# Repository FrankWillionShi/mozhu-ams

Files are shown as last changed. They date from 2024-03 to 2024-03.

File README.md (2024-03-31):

# MOZHU-AMS

#### 介绍
这是一个DIY 3D打印多色供料系统的项目，主要针对的是拓竹的P1系列，理论上X1系列也是可以用的。
输入图片说明 完整效果
这是项目第一次测试通过并且实现自动换料打印时拍摄的完整系统图片  
输入图片说明

#### 引用项目
该项目引用了B站up主不死鳥の守り的DIY AMS项目，非常感谢他开源的基于拓竹MQTT接口进行通信的设计方案和硬件结构设计，本方案才能最终落地  

输入图片说明 屏幕截图  
在本项目中，引用了这位UP主的AMS模型设计（1.2版）和拓竹MQTT的部分指令，模型设计在本开源项目的hardware文件夹中的AMS组件.3mf中，MQTT指令在代码中有所体现。

#### 项目说明

1.  本项目使用无上位机的设计，使用合宙esp32C3核心板作为主控，理论上一个主控可以控制最多四个通道的耗材。
2.  本项目为开源项目，欢迎所有对此感兴趣的人一起建设。
3.  本项目还有许多不完善的地方，日后会陆续完善，欢迎大家批评指导。

#### 文件说明

1.  hardware文件夹中包含了引用的AMS进退料组件模型，进料缓冲器模型和断料检测模型，五通受限于本人建模技术较差，是买的成品，理论上可以直接买一个A1的五通拿来用。
2.  software文件夹中包含了本项目中使用到的代码，其中filamentChange.gcode是用来替换拓竹的换料GCODE的，直接在打印机设置中复制替换就可以，主要作用是降低换料过程的复杂性，这段代码可以让打印机完成切料、退料、进料、冲洗。请注意，直接编写GCODE控制打印机是很危险的，操作不当会有很大可能导致打印机出现机械故障，所以你如果对3D打印机的gcode没有深入了解，请尽量不要做修改。software中的AMSwithESP32是本项目的代码，基于Arduino IDE编写，其中包含了一个defines.h，这个文件中包含着用户设置，使用前请在这里设置wifi SSID、密码、打印机IP、打印机的链接授权码（八位数字）以及使用的通道数量，请尽可能不要修改除user setting以外的其他设置，否则有可能导致代码无法正常运行。
3.bambu_ca.pem是本开原作者提取到自己打印机中的CA证书，并用其生成了finger point来连接打印机，如果你连上网以后无法连接到打印机的MQTT端口，在确认IP没有出错的前提下，可以使用以下指令来生成finger point并对代码进行修改：  
openssl s_client -connect your_server_address:port -showcerts | openssl x509 -noout -fingerprint

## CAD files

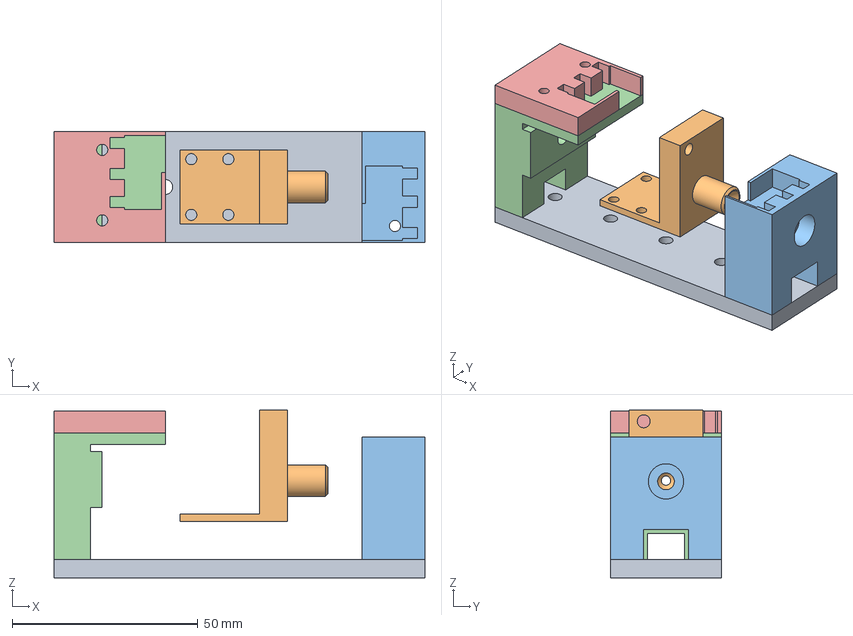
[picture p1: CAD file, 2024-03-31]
hardware/进料缓冲器.3mf
100.0 x 30.0 x 45.2 mm

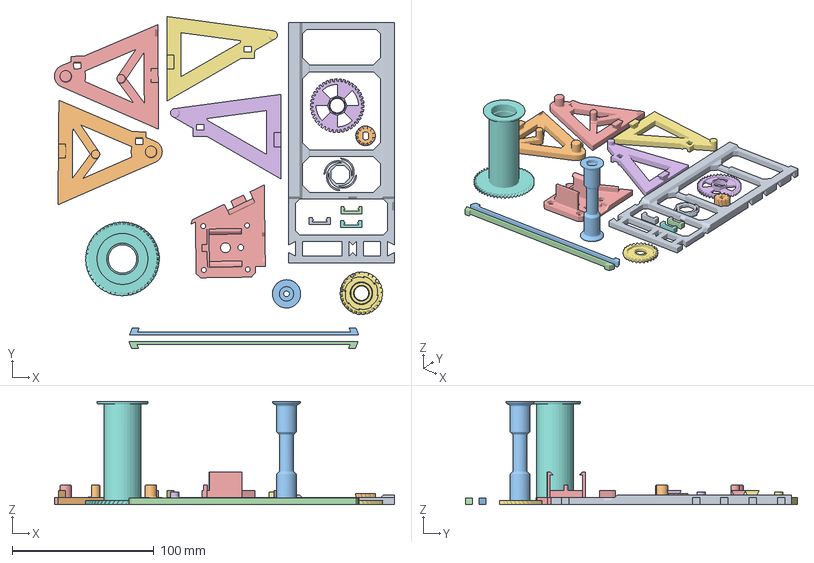
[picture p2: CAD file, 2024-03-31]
hardware/AMS组件.3mf
240.2 x 234.4 x 73.0 mm
底座
侧边 主动(单边) x 2
加强筋 1 x 2
电机固定座
棘轮 外
棘轮 内
滚轮 主动
棘轮 中
电机轴齿
滚轮 被动
缓冲器卡扣 x 3
侧边 被动(单边 右侧) x 2

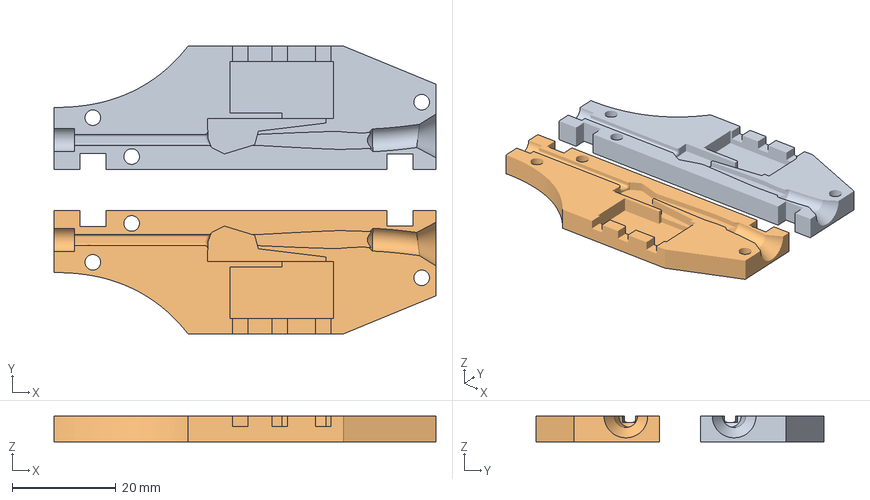
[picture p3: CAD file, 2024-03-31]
hardware/断料检测器.3mf
73.8 x 55.6 x 5.00 mm

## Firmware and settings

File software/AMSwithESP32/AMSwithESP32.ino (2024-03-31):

#define ASYNC_TCP_SSL_ENABLED 1
#define MQTT_SECURE 1
#include "defines.h"
#include <WiFi.h>
#include <ArduinoJson.h>
#include <AsyncMQTT_ESP32.h>
extern "C"
{
#include "freertos/FreeRTOS.h"
#include "freertos/timers.h"
}



//*******************Global Parameters begin********************
AsyncMqttClient mqttClient;
TimerHandle_t mqttReconnectTimer;
TimerHandle_t wifiReconnectTimer;
int Filament_Now = 0;
int FilaMent_Next = -1;
uint8_t workstate = 0;
bool Buffer_Func_Flag = 0;
bool ams_require_received = 0;
bool buffer_once_flag = 0;
const std::string bambu_resume = R"({"print":{"command":"resume","sequence_id":"1"},"user_id":"1"})";
const std::string bambu_unload = R"({"print":{"command":"ams_change_filament","curr_temp":220,"sequence_id":"1","tar_temp":220,"target":255},"user_id":"1"})";
const std::string bambu_load = R"({"print":{"command":"ams_change_filament","curr_temp":220,"sequence_id":"1","tar_temp":220,"target":254},"user_id":"1"})";
const std::string bambu_done = R"({"print":{"command":"ams_control","param":"done","sequence_id":"1"},"user_id":"1"})";
bool mqttDataReadyFlag = 0;
JsonDocument jsonRecv;
bool unloadFlag = 0;
bool sameFilamentFlag = 0;
int unloadCount = 0;
bool resumeCallbackFlag = 0;
int pwmtimer = 0;
//*******************Global Parameters end*********************

//*******************private functions begin*******************
void systeminit();
void connectToWifi();
void connectToMqtt();
void WiFiEvent(WiFiEvent_t event);
void printSeparationLine();
void onMqttConnect(bool sessionPresent);
void onMqttDisconnect(AsyncMqttClientDisconnectReason reason);
void onMqttSubscribe(const uint16_t& packetId, const uint8_t& qos);
void onMqttUnsubscribe(const uint16_t& packetId);
void onMqttMessage(char* topic, char* payload, const AsyncMqttClientMessageProperties& properties,
                   const size_t& len, const size_t& index, const size_t& total);
void onMqttPublish(const uint16_t& packetId);
void filament_buffer_func();
bool checkPauseFlag(JsonDocument& doc);
bool checkNextFilament(JsonDocument& doc,int& nextfilament);
void coreThread();
bool sendResaumeCallback();
bool checkHWSwitch(JsonDocument& doc);
void unloadBufferCallback();
void PWMGenerate(int GPIO,int threshold);
void PWMTimer();
//*******************private functions end*********************

void setup()
{
  systeminit();
}

void loop()
{
  coreThread();
}

void systeminit()
{
  // init string
  Listen_Topic = std::string("device/") + BambuLab_Serial + Listen_Topic;
  Public_Topic = std::string("device/") + BambuLab_Serial + Public_Topic;

  // init serial and print version data
  Serial.begin(115200);

  while (!Serial && millis() < 5000);

  delay(500);

  Serial.print("\n[log]Starting mozhu-AMS on ");
  Serial.println(ARDUINO_BOARD);
  Serial.print("[log]");
  Serial.println(ASYNC_MQTT_ESP32_VERSION);

  // init timer
  mqttReconnectTimer = xTimerCreate("mqttTimer", pdMS_TO_TICKS(2000), pdFALSE, (void*)0,
                                    reinterpret_cast<TimerCallbackFunction_t>(connectToMqtt));
  wifiReconnectTimer = xTimerCreate("wifiTimer", pdMS_TO_TICKS(2000), pdFALSE, (void*)0,
                                    reinterpret_cast<TimerCallbackFunction_t>(connectToWifi));

  //init callback
  WiFi.onEvent(WiFiEvent);

  mqttClient.setCredentials(username,password);
  mqttClient.onConnect(onMqttConnect);
  mqttClient.onDisconnect(onMqttDisconnect);
  mqttClient.onSubscribe(onMqttSubscribe);
  mqttClient.onUnsubscribe(onMqttUnsubscribe);
  mqttClient.onMessage(onMqttMessage);
  mqttClient.onPublish(onMqttPublish);

  //init server
  mqttClient.setServer(MQTT_HOST, MQTT_PORT);

  mqttClient.setSecure(MQTT_SECURE);

  if (MQTT_SECURE)
  {
    //mqttClient.addServerFingerprint((const uint8_t[])MQTT_SERVER_FINGERPRINT);
    mqttClient.addServerFingerprint((const uint8_t *)MQTT_SERVER_FINGERPRINT);
  }

  connectToWifi();

  //init GPIO
  for(int i = 0; i < 4; i++)
  {
    pinMode(Motor_Forward[i],OUTPUT);
    digitalWrite(Motor_Forward[i],0);
    pinMode(Motor_Bacword[i],OUTPUT);
    digitalWrite(Motor_Bacword[i],0);
    pinMode(Filament_detection[i],INPUT_PULLDOWN);
  }
  pinMode(Buffer_Detection[0],INPUT_PULLDOWN);
  pinMode(Buffer_Detection[1],INPUT_PULLDOWN);
  Serial.println("[log]GPIO init complete\n");

  //init filament
  if(!JUMP_FILAMENT_INIT)
  {
    if(Filament_Num > 4)
      Filament_Num = 4;
    if(Filament_Num < 1)
      Filament_Num = 1;
    for(int i = 0; i < Filament_Num; i++)
    {
      //make sure the filament is installed correctly
      Serial.print("[log]Filament No.");
      Serial.print(i);
      Serial.println("input");
      digitalWrite(Motor_Forward[i], 1);
      while(!digitalRead(Filament_detection[i])) {};
      Serial.print("[log]Filament No.");
      Serial.print(i);
      Serial.println("output");
      digitalWrite(Motor_Forward[i],0);
      digitalWrite(Motor_Bacword[i],1);
      while(digitalRead(Filament_detection[i])) {};
      digitalWrite(Motor_Bacword[i],0);
      Serial.print("[log]Filament No.");
      Serial.print(i);
      Serial.println("complete");
    }
    Serial.println("[log]filament init complete\n");
  }

}

void connectToWifi()
{
  Serial.println("[log]Connecting to Wi-Fi...");
  WiFi.begin(WIFI_SSID, WIFI_PASSWORD);
}

void connectToMqtt()
{
  Serial.println("[log]Connecting to MQTT...");
  mqttClient.connect();
}

void WiFiEvent(WiFiEvent_t event)
{
  switch (event)
  {
#if USING_CORE_ESP32_CORE_V200_PLUS

    case ARDUINO_EVENT_WIFI_READY:
      Serial.println("[log]WiFi ready");
      break;

    case ARDUINO_EVENT_WIFI_STA_START:
      Serial.println("[log]WiFi STA starting");
      break;

    case ARDUINO_EVENT_WIFI_STA_CONNECTED:
      Serial.println("[log]WiFi STA connected");
      break;

    case ARDUINO_EVENT_WIFI_STA_GOT_IP6:
    case ARDUINO_EVENT_WIFI_STA_GOT_IP:
      Serial.println("[log]WiFi connected");
      Serial.print("[log]IP address: ");
      Serial.println(WiFi.localIP());
      connectToMqtt();
      break;

    case ARDUINO_EVENT_WIFI_STA_LOST_IP:
      Serial.println("[log]WiFi lost IP");
      break;

    case ARDUINO_EVENT_WIFI_STA_DISCONNECTED:
      Serial.println("[log]WiFi lost connection");
      xTimerStop(mqttReconnectTimer, 0); // ensure we don't reconnect to MQTT while reconnecting to Wi-Fi
      xTimerStart(wifiReconnectTimer, 0);
      break;
#else

    case SYSTEM_EVENT_STA_GOT_IP:
      Serial.println("[log]WiFi connected");
      Serial.print("[log]IP address: ");
      Serial.println(WiFi.localIP());
      connectToMqtt();
      break;

    case SYSTEM_EVENT_STA_DISCONNECTED:
      Serial.println("[log]WiFi lost connection");
      xTimerStop(mqttReconnectTimer, 0); // ensure we don't reconnect to MQTT while reconnecting to Wi-Fi
      xTimerStart(wifiReconnectTimer, 0);
      break;
#endif

    default:
      break;
  }
}

void printSeparationLine()
{
  Serial.println("************************************************");
}

void onMqttConnect(bool sessionPresent)
{
  Serial.print("[log]Connected to MQTT broker: ");
  Serial.print(MQTT_HOST);
  Serial.print(", port: ");
  Serial.println(MQTT_PORT);
  Serial.print("PubTopic: ");
  Serial.println(Listen_Topic.c_str());

  printSeparationLine();
  Serial.print("[log]Session present: ");
  Serial.println(sessionPresent);

  uint16_t packetIdSub = mqttClient.subscribe(Listen_Topic.c_str(), 0);
  Serial.print("[log]Subscribing at QoS 0, packetId: ");
  Serial.println(packetIdSub);

  printSeparationLine();
}

void onMqttDisconnect(AsyncMqttClientDisconnectReason reason)
{
  (void) reason;

  Serial.println("[log]Disconnected from MQTT.");

  if (WiFi.isConnected())
  {
    xTimerStart(mqttReconnectTimer, 0);
  }
}

void onMqttSubscribe(const uint16_t& packetId, const uint8_t& qos)
{
  Serial.println("[log]Subscribe acknowledged.");
  Serial.print("  packetId: ");
  Serial.println(packetId);
  Serial.print("  qos: ");
  Serial.println(qos);
}

void onMqttUnsubscribe(const uint16_t& packetId)
{
  Serial.println("[log]Unsubscribe acknowledged.");
  Serial.print("  packetId: ");
  Serial.println(packetId);
}

void onMqttMessage(char* topic, char* payload, const AsyncMqttClientMessageProperties& properties,
                   const size_t& len, const size_t& index, const size_t& total)
{
  if(SHOW_RECEIVE_LOG)
  {
    Serial.println("[log]Publish received.");
    Serial.print("  topic: ");
    Serial.println(topic);
    Serial.print("  qos: ");
    Serial.println(properties.qos);
    Serial.print("  dup: ");
    Serial.println(properties.dup);
    Serial.print("  retain: ");
    Serial.println(properties.retain);
    Serial.print("  len: ");
    Serial.println(len);
    Serial.print("  index: ");
    Serial.println(index);
    Serial.print("  total: ");
    Serial.println(total);
  }

  if(SHOW_RECEIVE_DETAIL)
  {
    Serial.println(payload);
  }
  
  if(!mqttDataReadyFlag)
  {
    if(SHOW_MQTT_DECODE_DETAIL)
    {
      Serial.println("receive a mqtt pack and decode successfully");
    }
    deserializeJson(jsonRecv,(char*)payload,len);
    mqttDataReadyFlag = 1;
  }
  else
  {
    if(SHOW_MQTT_DECODE_DETAIL)
    {
      Serial.println("receive a mqtt pack but decode not allowed");
    }
  }
  
}

void onMqttPublish(const uint16_t& packetId)
{
  Serial.println("[log]Publish acknowledged");
  Serial.print("  packetId: ");
  Serial.println(packetId);
}

void filament_buffer_func()
{
  if(workstate == 0)
  {
    if(digitalRead(Buffer_Detection[1]))
    {
      Buffer_Func_Flag = 1;
      digitalWrite(Motor_Forward[Filament_Now], 1);
      if(SHOW_INPUT_BUFFER_DETAIL)
      {
        if(!buffer_once_flag)
        {
          Serial.println("[debug]input buffer func begin");
          buffer_once_flag = 1;
        }
      }   
    }
    if(digitalRead(Buffer_Detection[0]) == 1 && Buffer_Func_Flag == 1)
    {
      digitalWrite(Motor_Forward[Filament_Now], 0);
      Buffer_Func_Flag = 0;
      if(SHOW_INPUT_BUFFER_DETAIL)
       Serial.println("[debug]input buffer func end");
      buffer_once_flag = 0;
    }
  }
}

bool checkNextFilament(JsonDocument& doc,int& nextfilament)
{
  JsonObject print = doc["print"];

  int print_mc_percent = print["mc_percent"]; // 101 + next filament
  if(print_mc_percent > 100)
  {
    nextfilament = print_mc_percent - 101;
    if(SHOW_FILAMENT_CHECK_DETAIL)
    {
      Serial.println("next filament received");
    }
    return 1;
  }
  else
  {
    if(SHOW_FILAMENT_CHECK_DETAIL)
    {
      Serial.println("next filament not found");
    }
    return 0;
  }
}

void unloadBufferCallback()
{
  if(digitalRead(Buffer_Detection[0]))
  {
    digitalWrite(Motor_Bacword[Filament_Now], 1);
    if(SHOW_OUTPUT_BUFFER_DETAIL)
    {
      if(!buffer_once_flag)
      {
        Serial.println("[debug]output buffer func begin");
        buffer_once_flag = 1;
      }
    }   
  }
  if(digitalRead(Buffer_Detection[1]))
  {
    digitalWrite(Motor_Bacword[Filament_Now], 0);
    if(SHOW_OUTPUT_BUFFER_DETAIL && buffer_once_flag)
      Serial.println("[debug]output buffer func end");
    buffer_once_flag = 0;
  }
}

bool sendResaumeCallback()
{
  if(digitalRead(Buffer_Detection[0]))
  {
    mqttClient.publish(Public_Topic.c_str(),0,0,bambu_resume.c_str(),bambu_resume.size());
    return 1;
  }
  else
    return 0;
}

bool checkHWSwitch(JsonDocument& doc)
{
  JsonObject print = doc["print"];
  int print_hw_switch_state = print["hw_switch_state"]; // 1
  if(print_hw_switch_state == 1)
    return 1;
  else 
    return 0;
}

void PWMTimer()
{
  pwmtimer += 1;
  if(pwmtimer == 10)
    pwmtimer = 0;
}

void PWMGenerate(int GPIOX,int threshold)
{
  if(threshold % 10 > pwmtimer)
    digitalWrite(GPIOX, 0);
  else
    digitalWrite(GPIOX, 1);
}

void coreThread()
{  
  //workstate:
  //0: standby
  //1: AMS unloading
  //2: AMS loading
  //3: same filament buffering


  // filament buffer function
  filament_buffer_func();

  // AMS FUNCTION
  //if no MQTT data receive, skip this function
  if(mqttDataReadyFlag && workstate == 0)
  {
    if(checkNextFilament(jsonRecv,FilaMent_Next))
    {
      if(SHOW_AMS_REQUIRE)
        Serial.printf("[log]AMS require received\n");
      if(Buffer_Func_Flag)
      {
        //if the filament buffer function enable motor running, stop the motor and clear flag
        digitalWrite(Motor_Forward[Filament_Now],0);
        Buffer_Func_Flag = 0;
      }
      if(Filament_Now == FilaMent_Next)
      {
        Serial.println("[log]next filament is the same with the current filament,there is no need to change filament\n");
        unloadCount = 30000;
        sameFilamentFlag = 1;
        workstate = 3;
      }
      else
      {
        // enable motor to unload filament
        if(SHOW_FILAMENT_NUM)
          Serial.printf("[debug]filament change require received, start unloading filament\nfilament now is %d, filament next is %d \n",Filament_Now,FilaMent_Next);
        workstate = 4;
        unloadCount = 23000;
        unloadFlag = 1;
      }
    }
    else 
    {
      if(SHOW_NOAMS_REQUIRE)
        Serial.printf("[debug]No AMS require received\n");
    }
  }
  else if(workstate == 1)
  {
    // wait until filament is unload into AMS
    if(digitalRead(Filament_detection[Filament_Now]) == 0)
    {
      unloadFlag = 0;
      Serial.printf("[log]filament unload complete, start load new filament\n");
      // if the filament switch is off,it means the filament is back into AMS successfully
      // stop unload motor
      digitalWrite(Motor_Bacword[Filament_Now],0);
      Filament_Now = -1;
      // enable motor to send new filament into printer 
      digitalWrite(Motor_Forward[FilaMent_Next],1);
      workstate = 2;
    }
  }
  else if(workstate == 2)
  {
    // wait until filament buffer is full
    // Warning: When the resistance along the path of consumable filament to the printer is too high, it may cause the feeding to be prematurely stopped
    if(checkHWSwitch(jsonRecv))
    {
      Serial.printf("[log]filament load complete, sending command to printer\n");
      digitalWrite(Motor_Forward[FilaMent_Next], 0);
      // filament change is complete, send command to printer and updata filament data
      Filament_Now = FilaMent_Next;
      FilaMent_Next = -1;
      mqttClient.publish(Public_Topic.c_str(),0,0,bambu_resume.c_str(),bambu_resume.size());
      workstate = 0;
      //resumeCallbackFlag = 1;
    }
    else 
    {
      if(digitalRead(Buffer_Detection[0]))
        PWMGenerate(Motor_Forward[FilaMent_Next], 5);
      else
        digitalWrite(Motor_Forward[FilaMent_Next], 1);
    }
  }

  //system callback
  //unload callback
  if(unloadCount > 0)
  {
    unloadCount -= 1;
    unloadBufferCallback();
  }
  else if(unloadFlag)
  {
    Serial.println("[log]filament unload start\n");
    digitalWrite(Motor_Bacword[Filament_Now],1);
    workstate = 1;
  }
  else if(sameFilamentFlag)
  {
    mqttClient.publish(Public_Topic.c_str(),0,0,bambu_resume.c_str(),bambu_resume.size());
    Serial.println("[log]command resume send complete\n");
    workstate = 0;
    sameFilamentFlag = 0;
  }
  //load callback
  if(SHOW_MQTT_FLAG && mqttDataReadyFlag)
  {
    Serial.println("[debug]MQTT pack received");
  }
  mqttDataReadyFlag = 0;
  PWMTimer();
  delay(1);
}

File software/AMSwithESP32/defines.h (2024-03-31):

#ifndef MOZHU_AMS_SETTINGS
#define MOZHU_AMS_SETTINGS

#define _ASYNC_MQTT_LOGLEVEL_               1
#include <string.h>

// *****************User Settings begin***********************

#define WIFI_SSID         "robomaster109"
#define WIFI_PASSWORD     "robo123456"
#define MQTT_HOST         IPAddress(192, 168, 0, 100)
const char* password = "24282340";
std::string BambuLab_Serial = "01S00C351400077";
int Filament_Num = 2;
// *****************User Settings end***********************


// ****************default settings begin*********************
// Warning: do not edit these settings if not necessary
const uint8_t MQTT_SERVER_FINGERPRINT[] = {0x2E, 0xA1, 0xA1, 0x8B, 0x61, 0x42, 0xDB, 0x96, 0x8F, 0x41, 0x4D, 0x4B, 0x7D, 0xAF, 0x9A, 0x64, 0xD3, 0x3A, 0x42, 0x07};
const char* username = "bblp";
const int Motor_Forward[4] = {0,2,10,7};
const int Motor_Bacword[4] = {1,3,6,11};
const int Filament_detection[4] = {5,4,8,9};
const int Buffer_Detection[2] = {12,13};
std::string Listen_Topic = "/report";
std::string Public_Topic = "/request";
#define MQTT_PORT       8883
// ****************default settings end*********************

// ****************debug settings begin*********************
#define JUMP_FILAMENT_INIT 1
#define SHOW_RECEIVE_LOG 0
#define SHOW_RECEIVE_DETAIL 0
#define SHOW_AMS_REQUIRE 1
#define SHOW_NOAMS_REQUIRE 0
#define SHOW_MQTT_FLAG 0
#define SHOW_INPUT_BUFFER_DETAIL 1
#define SHOW_OUTPUT_BUFFER_DETAIL 1
#define SHOW_FILAMENT_NUM 1
#define SHOW_WORKSTATE 0
#define SHOW_MQTT_DECODE_DETAIL 0
#define SHOW_FILAMENT_CHECK_DETAIL 0
// ****************debug settings end***********************

#endif    //MOZHU_AMS_SETTINGS

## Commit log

2024-03-27 更换主控
2024-03-29 fix some bug, and by the way, fXXk you AMD
    [ams_esp32.ino, defines.h]
2024-03-31 add moudle
    [AMS组件.3mf, 断料检测器.3mf, 进料缓冲器.3mf]
